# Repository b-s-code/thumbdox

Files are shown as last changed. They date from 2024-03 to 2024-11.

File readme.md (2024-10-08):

# ThumbDox

The ThumbDox is a (WIP) split keyboard based on the [ErgoDox](https://www.ergodox.io/).

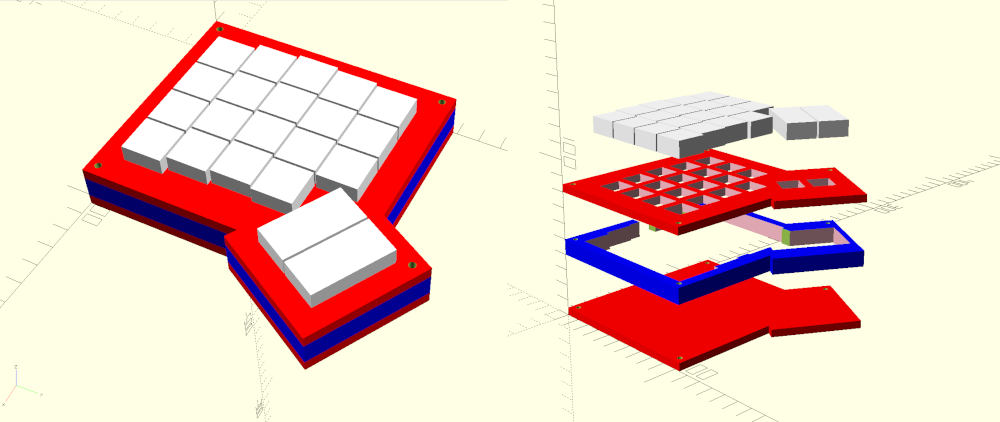
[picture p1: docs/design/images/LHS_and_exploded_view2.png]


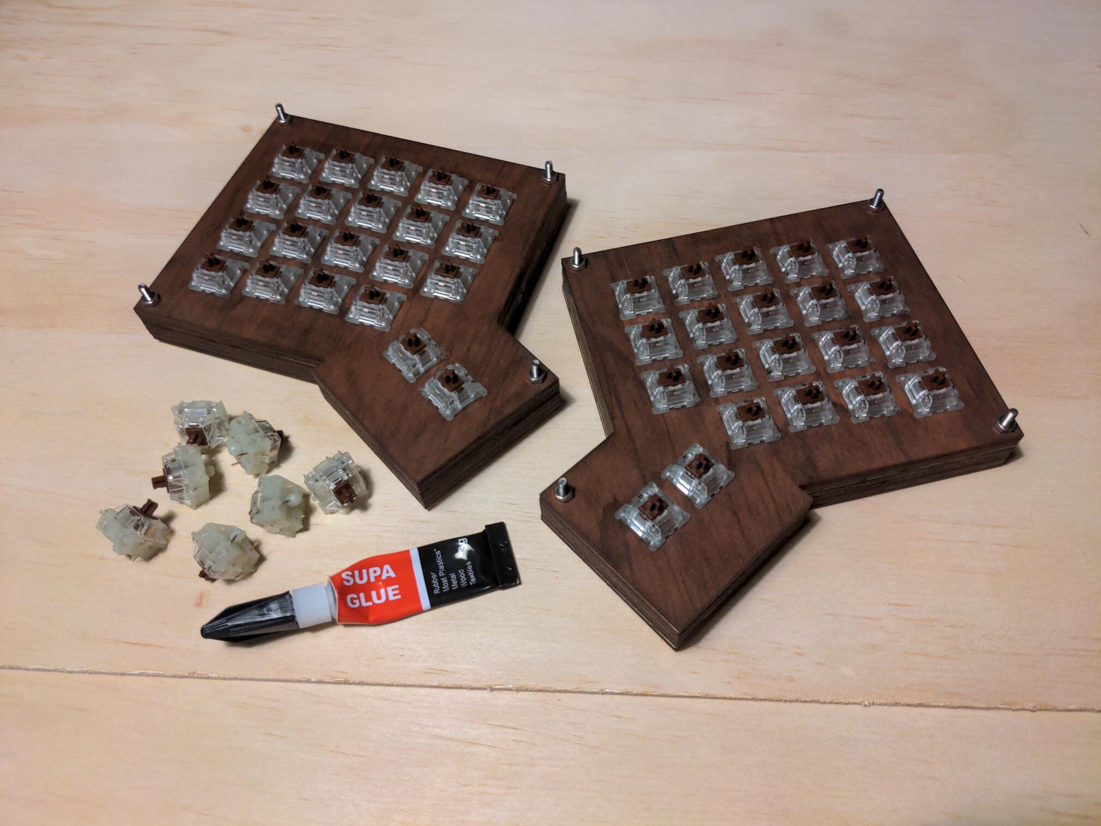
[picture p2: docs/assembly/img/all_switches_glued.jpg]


My aims in producing ThumbDox:

1.  Eliminate most of the keys I don't use.
2.  Retain the two 2U thumb keys.
3.  Document the design and production of the keyboard.  Many existing projects are similar, but I could not find anything exactly like what I wanted.  Perhaps showing my process here may save someone else reinventing the ThumbDox.

## Similar projects

[ErgoDox](https://www.ergodox.io/) [Squiggle](https://github.com/ibnuda/Squiggle) [Zen](https://legonut.gitbooks.io/zen-keyboard/content/) [Gergo](https://qmk.fm/keyboards/gergo/)

## Development

See [docs/design/dev_env_setup.md](docs/design/model_dev_env_setup.md) for details on going from Python source to DXF files suitable for laser cutting.

See [docs/design/qmk_dev_env_setup.md](docs/firmware/qmk_dev_env_setup.md) for details on working with the QMK firmware that powers ThumbDox.

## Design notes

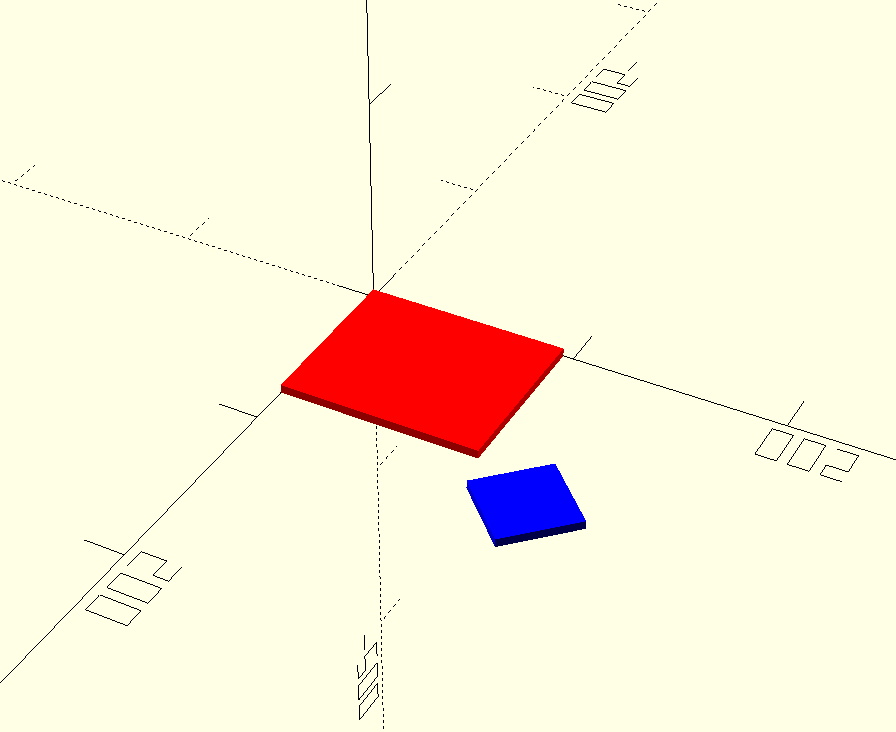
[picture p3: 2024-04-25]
docs/design/images/column_group_minuends_untuned_positions_no_padding.png

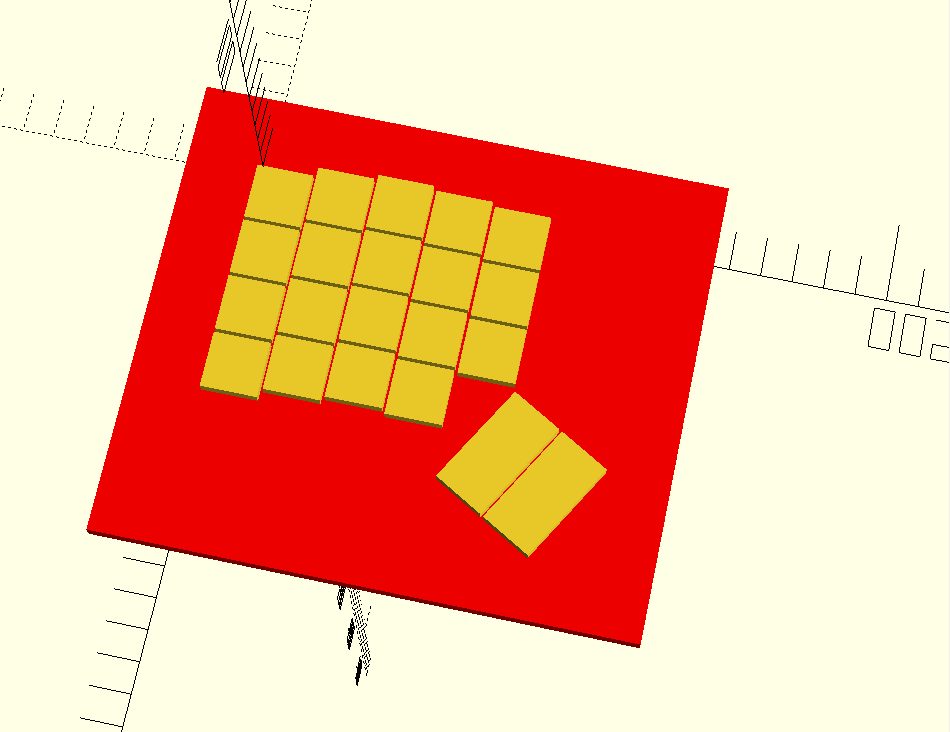
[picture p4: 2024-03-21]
docs/design/images/key_positions_tuned.png

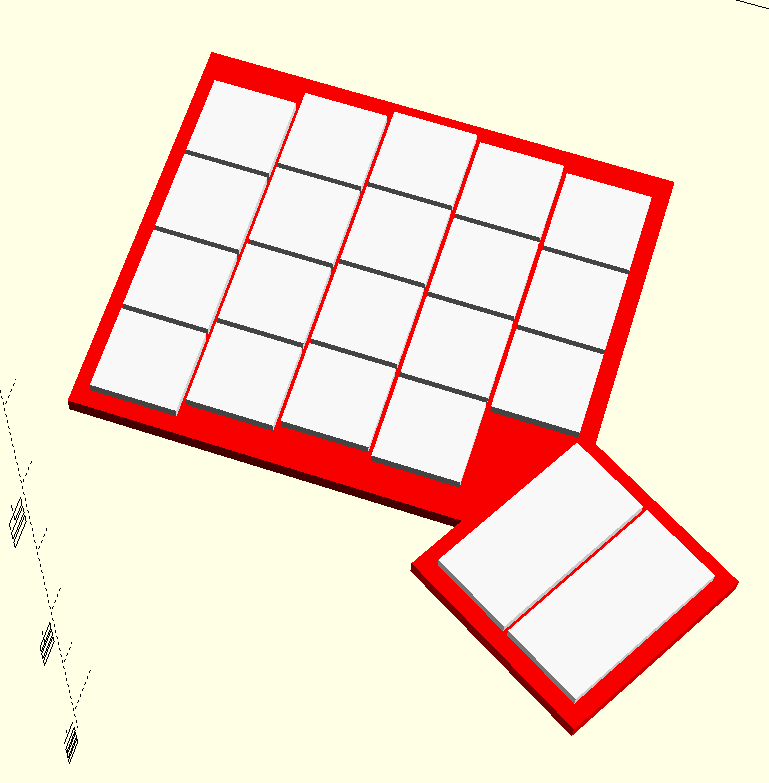
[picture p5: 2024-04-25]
docs/design/images/keycaps_and_base.png

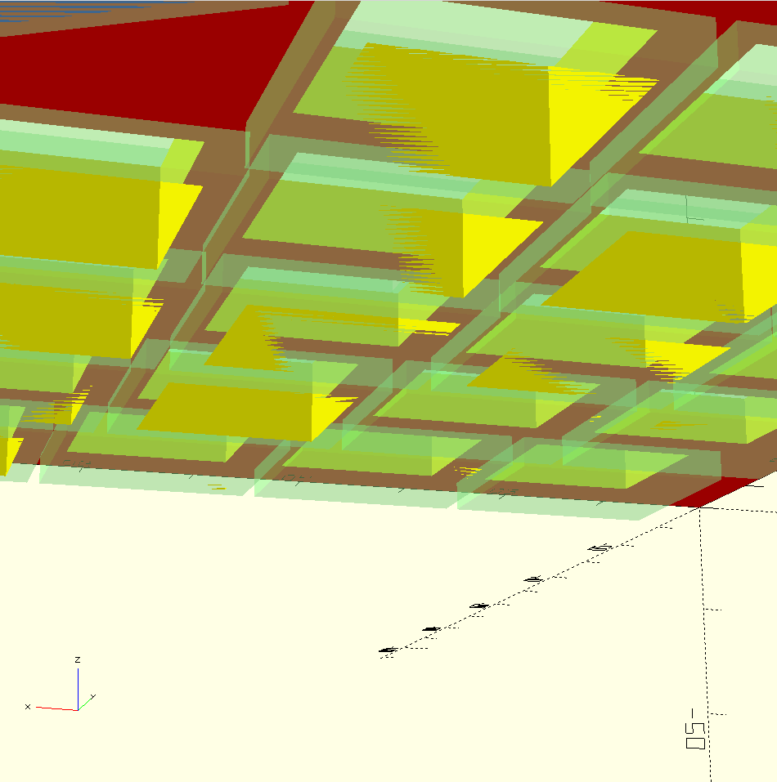
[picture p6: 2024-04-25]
docs/design/images/transparent_keycaps2.png

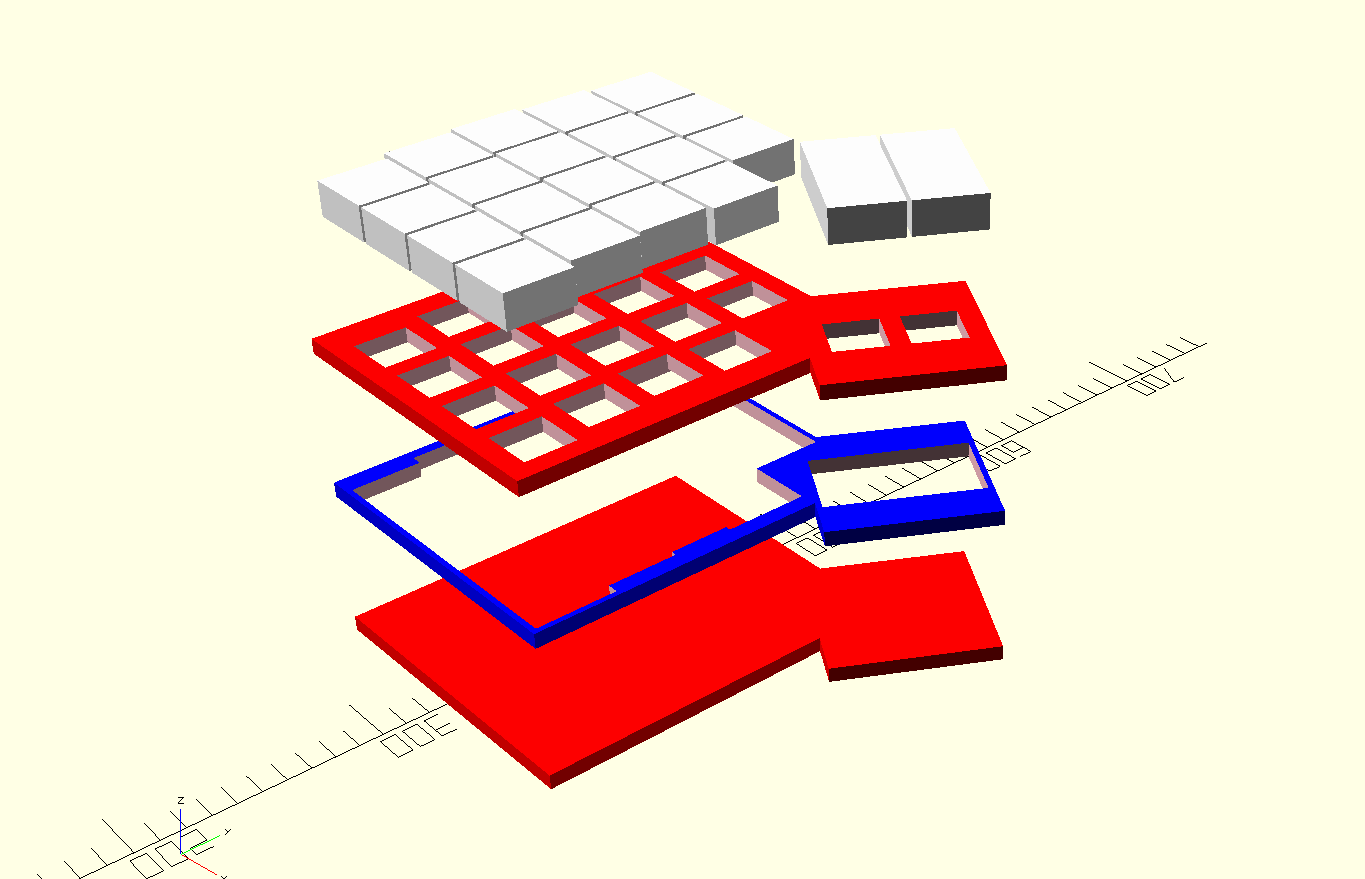
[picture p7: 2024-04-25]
docs/design/images/first_exploded_render.png

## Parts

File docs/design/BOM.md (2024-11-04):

# Bill of materials

## Parts

| Part | Description | Quantity | Unit cost | Cost | Source |
|---|---|---|---|---|---|
| 1N4148 Small Signal Diode | One of these diodes connects each keyswitch to a row wire. | 42 | $0.15 AUD | $6.30 AUD | https://www.altronics.com.au/p/z0101-1n914-1n4148-small-signal-diode/ |
| OEM Profile R1 Row1 Caps 1.25u/1.5u/1.75u/2.0u/2.25u/2.75u PBT Keycaps for Mechanical Keyboard Supplementary Keys Alt Ctrl Shift | Keycaps for thumb cluster. | 4 | - | $20.49 AUD | https://www.aliexpress.com/item/1005004784994416.html |
| OEM Profile 75 Key Blank PBT Ortholinear Layout Keycaps For Mechanical Keyboard XD75 ID75 Planck Preonic Niu40 YMD40v2 40% DIY | Keycaps for finger clusters.  Only need some of these. | 1 set | - | $37.95 AUD | https://www.aliexpress.com/item/1005001914177551.html |
| 10 100 Pcs TRRS 3.5 MM Audio Jack Connector Through Holes PCB Horizontal 4 Conductor Right Angle No Internal Switch 4 Pole | TRRS jack set, only need 2 pieces. | 1 set | - | $6.11 AUD | https://www.aliexpress.com/item/33029465106.html |
| Raspberry Pi Pico microcontroller | One for each keyboard half. | 2 | $8.95 AUD | $17.90 AUD | https://www.altronics.com.au/p/z6421-raspberry-pi-pico-microcontroller-board/ |
| Male-male Micro USB to USB Type A cable | Connects main microcontroller to PC. | 1 | N/A | N/A | - |
| Male-male TRRS cable | Connects left and right halves of keyboard. | 1 | N/A | N/A | - |
| 3mm plywood 1200mm x 810mm | Gets laser cut to produce case and switch plate parts. | 1 | $18.00 AUD | $18.00 AUD | Bunnings |
| M3 x 25mm bolts and nuts | Joins case and switch plate layers - requires head diameter <=6mm, thread length >20mm. | 8 | N/A | $3.90 AUD | https://www.bunnings.com.au/pinnacle-m3-x-25mm-stainless-steel-hex-head-bolts-and-nuts-12-pack_p0247296 |
| Original Brand NEW Cherry MX Mechanical Keyboard Switches Silver Red Black Blue Brown Linear Tactile Cherry Clear SMD RGB Switch | Brown MX compatible key switches. | 42 (bought 60) | ~$0.30 AUD | $17.91 AUD | https://www.aliexpress.com/item/1005006255961111.html |

## Tools and general consumables

| Item | Notes |
|---|---|
| Soldering iron | - |
| Lead free solder | - |
| Knife | - |
| Hot glue gun | - |
| Hot glue | To fix MCU and TRRS jack in place. |
| Wire (insulated)  | - |
| Wire (uninsulated)  | - |
| Heat-shrink tubing  | - |

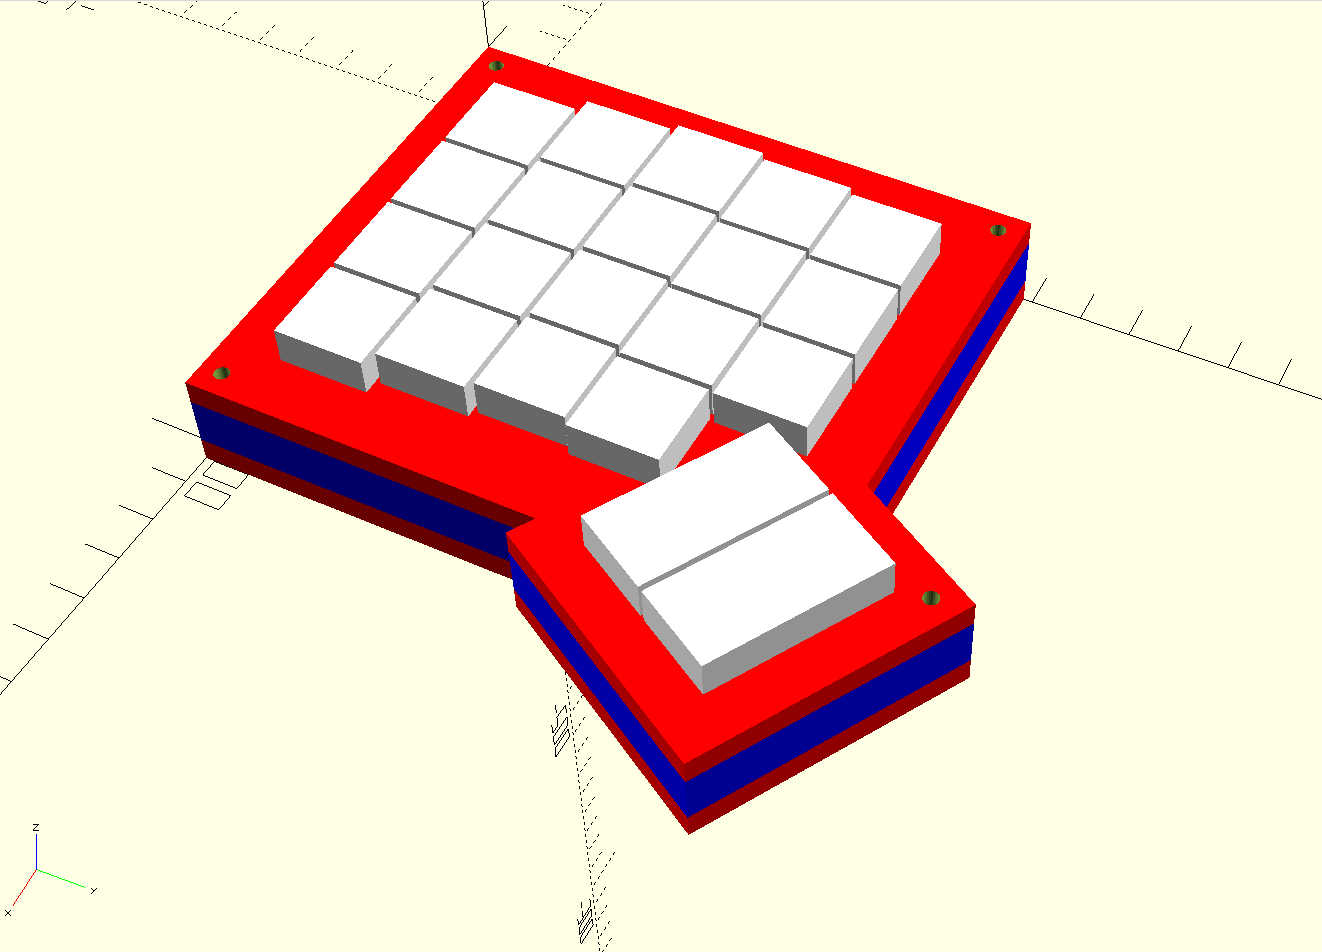
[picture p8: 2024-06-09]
docs/design/images/flush_parts3.png

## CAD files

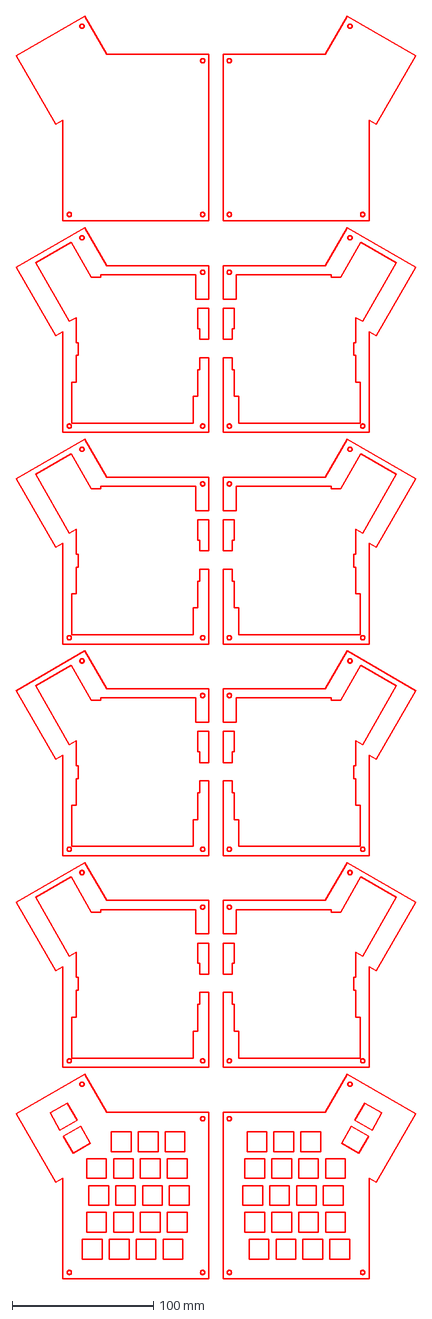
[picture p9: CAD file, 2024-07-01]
3D_model/concat_parts_3mm.dxf
283.3 x 895.1 mm

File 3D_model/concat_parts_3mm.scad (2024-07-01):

projection()
union() {
	cube(size = [0, 0, 0]);
	translate(v = [0, 0, 0]) {
		union() {
			difference() {
				union() {
					cube(size = [0, 0, 0]);
					color(alpha = 1.0, c = "red") {
						translate(v = [0.0, 0.0, 0]) {
							rotate(a = [0, 0, -0.0]) {
								cube(size = [103.7, 118.25, 5]);
							}
						}
					}
					color(alpha = 1.0, c = "red") {
						translate(v = [60.0, 96.5, 0]) {
							rotate(a = [0, 0, -30.0]) {
								cube(size = [56.1, 56.1, 5]);
							}
						}
					}
				}
				union() {
					cube(size = [0, 0, 0]);
					translate(v = [4.5, 4.5, -1]) {
						cylinder($fn = 30, h = 15, r = 1.5);
					}
					translate(v = [99, 4.5, -1]) {
						cylinder($fn = 30, h = 15, r = 1.5);
					}
					translate(v = [90, 138, -1]) {
						cylinder($fn = 30, h = 15, r = 1.5);
					}
					translate(v = [4.5, 113.5, -1]) {
						cylinder($fn = 30, h = 15, r = 1.5);
					}
					translate(v = [0.0, 0.0, 0]) {
						rotate(a = [0, 0, -0.0]) {
							union() {
								cube(size = [0, 0, 0]);
								translate(v = [16.0, 11.5, 0]) {
									color(alpha = 1.0, c = "pink") {
										translate(v = [2.5250000000000004, 2.5250000000000004, 0]) {
											translate(v = [0, 0, -2.5]) {
												cube(size = [14, 14, 10]);
											}
										}
									}
								}
								translate(v = [35.05, 11.5, 0]) {
									color(alpha = 1.0, c = "pink") {
										translate(v = [2.5250000000000004, 2.5250000000000004, 0]) {
											translate(v = [0, 0, -2.5]) {
												cube(size = [14, 14, 10]);
											}
										}
									}
								}
								translate(v = [54.1, 11.5, 0]) {
									color(alpha = 1.0, c = "pink") {
										translate(v = [2.5250000000000004, 2.5250000000000004, 0]) {
											translate(v = [0, 0, -2.5]) {
												cube(size = [14, 14, 10]);
											}
										}
									}
								}
								translate(v = [73.15, 11.5, 0]) {
									color(alpha = 1.0, c = "pink") {
										translate(v = [2.5250000000000004, 2.5250000000000004, 0]) {
											translate(v = [0, 0, -2.5]) {
												cube(size = [14, 14, 10]);
											}
										}
									}
								}
								translate(v = [13.0, 30.55, 0]) {
									color(alpha = 1.0, c = "pink") {
										translate(v = [2.5250000000000004, 2.5250000000000004, 0]) {
											translate(v = [0, 0, -2.5]) {
												cube(size = [14, 14, 10]);
											}
										}
									}
								}
								translate(v = [32.05, 30.55, 0]) {
									color(alpha = 1.0, c = "pink") {
										translate(v = [2.5250000000000004, 2.5250000000000004, 0]) {
											translate(v = [0, 0, -2.5]) {
												cube(size = [14, 14, 10]);
											}
										}
									}
								}
								translate(v = [51.1, 30.55, 0]) {
									color(alpha = 1.0, c = "pink") {
										translate(v = [2.5250000000000004, 2.5250000000000004, 0]) {
											translate(v = [0, 0, -2.5]) {
												cube(size = [14, 14, 10]);
											}
										}
									}
								}
								translate(v = [70.15, 30.55, 0]) {
									color(alpha = 1.0, c = "pink") {
										translate(v = [2.5250000000000004, 2.5250000000000004, 0]) {
											translate(v = [0, 0, -2.5]) {
												cube(size = [14, 14, 10]);
											}
										}
									}
								}
								translate(v = [11.5, 49.6, 0]) {
									color(alpha = 1.0, c = "pink") {
										translate(v = [2.5250000000000004, 2.5250000000000004, 0]) {
											translate(v = [0, 0, -2.5]) {
												cube(size = [14, 14, 10]);
											}
										}
									}
								}
								translate(v = [30.55, 49.6, 0]) {
									color(alpha = 1.0, c = "pink") {
										translate(v = [2.5250000000000004, 2.5250000000000004, 0]) {
											translate(v = [0, 0, -2.5]) {
												cube(size = [14, 14, 10]);
											}
										}
									}
								}
								translate(v = [49.6, 49.6, 0]) {
									color(alpha = 1.0, c = "pink") {
										translate(v = [2.5250000000000004, 2.5250000000000004, 0]) {
											translate(v = [0, 0, -2.5]) {
												cube(size = [14, 14, 10]);
											}
										}
									}
								}
								translate(v = [68.65, 49.6, 0]) {
									color(alpha = 1.0, c = "pink") {
										translate(v = [2.5250000000000004, 2.5250000000000004, 0]) {
											translate(v = [0, 0, -2.5]) {
												cube(size = [14, 14, 10]);
											}
										}
									}
								}
								translate(v = [13.0, 68.65, 0]) {
									color(alpha = 1.0, c = "pink") {
										translate(v = [2.5250000000000004, 2.5250000000000004, 0]) {
											translate(v = [0, 0, -2.5]) {
												cube(size = [14, 14, 10]);
											}
										}
									}
								}
								translate(v = [32.05, 68.65, 0]) {
									color(alpha = 1.0, c = "pink") {
										translate(v = [2.5250000000000004, 2.5250000000000004, 0]) {
											translate(v = [0, 0, -2.5]) {
												cube(size = [14, 14, 10]);
											}
										}
									}
								}
								translate(v = [51.1, 68.65, 0]) {
									color(alpha = 1.0, c = "pink") {
										translate(v = [2.5250000000000004, 2.5250000000000004, 0]) {
											translate(v = [0, 0, -2.5]) {
												cube(size = [14, 14, 10]);
											}
										}
									}
								}
								translate(v = [70.15, 68.65, 0]) {
									color(alpha = 1.0, c = "pink") {
										translate(v = [2.5250000000000004, 2.5250000000000004, 0]) {
											translate(v = [0, 0, -2.5]) {
												cube(size = [14, 14, 10]);
											}
										}
									}
								}
								translate(v = [14.5, 87.7, 0]) {
									color(alpha = 1.0, c = "pink") {
										translate(v = [2.5250000000000004, 2.5250000000000004, 0]) {
											translate(v = [0, 0, -2.5]) {
												cube(size = [14, 14, 10]);
											}
										}
									}
								}
								translate(v = [33.55, 87.7, 0]) {
									color(alpha = 1.0, c = "pink") {
										translate(v = [2.5250000000000004, 2.5250000000000004, 0]) {
											translate(v = [0, 0, -2.5]) {
												cube(size = [14, 14, 10]);
											}
										}
									}
								}
								translate(v = [52.6, 87.7, 0]) {
									color(alpha = 1.0, c = "pink") {
										translate(v = [2.5250000000000004, 2.5250000000000004, 0]) {
											translate(v = [0, 0, -2.5]) {
												cube(size = [14, 14, 10]);
											}
										}
									}
								}
							}
						}
					}
					translate(v = [60.0, 96.5, 0]) {
						rotate(a = [0, 0, -30.0]) {
							union() {
								cube(size = [0, 0, 0]);
								translate(v = [18.525, 9.0, 0]) {
									color(alpha = 1.0, c = "pink") {
										translate(v = [2.5250000000000004, 2.5250000000000004, 0]) {
											translate(v = [0, 0, -2.5]) {
												cube(size = [14, 14, 10]);
											}
										}
									}
								}
								translate(v = [18.525, 28.05, 0]) {
									color(alpha = 1.0, c = "pink") {
										translate(v = [2.5250000000000004, 2.5250000000000004, 0]) {
											translate(v = [0, 0, -2.5]) {
												cube(size = [14, 14, 10]);
											}
										}
									}
								}
							}
						}
					}
				}
			}
			translate(v = [-10, 0, 0]) {
				mirror(v = [1, 0, 0]) {
					difference() {
						union() {
							cube(size = [0, 0, 0]);
							color(alpha = 1.0, c = "red") {
								translate(v = [0.0, 0.0, 0]) {
									rotate(a = [0, 0, -0.0]) {
										cube(size = [103.7, 118.25, 5]);
									}
								}
							}
							color(alpha = 1.0, c = "red") {
								translate(v = [60.0, 96.5, 0]) {
									rotate(a = [0, 0, -30.0]) {
										cube(size = [56.1, 56.1, 5]);
									}
								}
							}
						}
						union() {
							cube(size = [0, 0, 0]);
							translate(v = [4.5, 4.5, -1]) {
								cylinder($fn = 30, h = 15, r = 1.5);
							}
							translate(v = [99, 4.5, -1]) {
								cylinder($fn = 30, h = 15, r = 1.5);
							}
							translate(v = [90, 138, -1]) {
								cylinder($fn = 30, h = 15, r = 1.5);
							}
							translate(v = [4.5, 113.5, -1]) {
								cylinder($fn = 30, h = 15, r = 1.5);
							}
							translate(v = [0.0, 0.0, 0]) {
								rotate(a = [0, 0, -0.0]) {
									union() {
										cube(size = [0, 0, 0]);
										translate(v = [16.0, 11.5, 0]) {
											color(alpha = 1.0, c = "pink") {
												translate(v = [2.5250000000000004, 2.5250000000000004, 0]) {
													translate(v = [0, 0, -2.5]) {
														cube(size = [14, 14, 10]);
													}
												}
											}
										}
										translate(v = [35.05, 11.5, 0]) {
											color(alpha = 1.0, c = "pink") {
												translate(v = [2.5250000000000004, 2.5250000000000004, 0]) {
													translate(v = [0, 0, -2.5]) {
														cube(size = [14, 14, 10]);
													}
												}
											}
										}
										translate(v = [54.1, 11.5, 0]) {
											color(alpha = 1.0, c = "pink") {
												translate(v = [2.5250000000000004, 2.5250000000000004, 0]) {
													translate(v = [0, 0, -2.5]) {
														cube(size = [14, 14, 10]);
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

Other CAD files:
3D_model/full_model.scad
3D_model/model.scad

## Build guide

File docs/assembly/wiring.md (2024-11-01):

# Wiring

This document details wiring:

- within each keyboard half
 - i.e. how rows/columns are connected to each MCU
- between the two keyboard halves
 - i.e. how each MCU is is wired to its respective TRRS jack

## Software support for split keyboards

Won't flesh this out fully here since it's a wiring doc.  But there is code required to set this up.  See:

- https://docs.qmk.fm/features/split_keyboard
- https://docs.qmk.fm/drivers/serial

## TRRS connections

### TRRS communication mode

Each MCU needs a TRRS jack wired to it.

The Raspberry Pi Pico cannot use I2C over the TRRS connection because it is not supported (either in QMK or at all, not sure which).

Thus, serial communication must be used instead.

Pull up resistors are not required since using serial rather than I2C.

Note: ThumbDox uses *full duplex* serial communication (2 wires) which is purportedly faster.  It's unclear whether this is really necessary in practice.

### Which MCU pins can be used for connecting to TRRS jacks?

Let's consider, from the primary MCU's perspective, the purpose of the 4 wires between the two keyboard halves.

1. wire for transmitting data to the secondary MCU 
2. wire for receiving data from the secondary MCU
3. wire for ground
4. wire for supplying power to the secondary MCU

1, 2, and 3 can be wired to GPIO/ground pins.  But which pin to use for 4 is less clear.

Some split keyboards using Pico MCUs have VSYS wired to VSYS.  Others have 3v3 wired to 3v3.

People online argue about what's "right".  Neither setup is unanimously considered "preferred" or even "unambiguously okay".

Somewhat arbitrarily, 3v3 to 3v3 has been selected as the wiring scheme for supplying ThumbDox's secondary MCU with power.

## MCU pin assignment scheme

Note:

- "Centre-most" means centre of the two halves.  Not centre of one half of the keyboard.
- Thumb keys exist on their own row.
- Centre-most thumb key is wired to centre-most index column.
- The other thumb key is wired to home index column.

| Pin number | Pin name | Use |
|----|-----|----|
| 38 | GND | TRRS - ground |
| 36 | 3V3(OUT) | TRRS - power transmission |
| 1  | GP0 | Serial TX |
| 2  | GP1 | Serial RX |
| 16 | GP12 | Top row |
| 17 | GP13 | Home row |
| 19 | GP14 | Below home row |
| 20 | GP15 | Bottom row |
| 15 | GP11 | Thumb row |
| 26 | GP20 | Pinky column |
| 25 | GP19 | Ring column |
| 24 | GP18 | Middle column |
| 22 | GP17 | Index home column |
| 21 | GP16 | Index centre-most column |

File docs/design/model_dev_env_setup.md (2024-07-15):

# Setting up the development environment for 3D modelling

The [solidpython2 library](https://github.com/jeff-dh/SolidPython) is used to generate OpenSCAD code.

OpenSCAD is used to define the 3D models.

## Setup steps

### Install OpenSCAD

I installed OpenSCAD version 2021.01 with:

```
$ sudo apt-get install openscad
```

### Set up Python environment for generating OpenSCAD code

```
# cd to root of ThumbDox repo.

# Create a virtual environment to install dependencies.
$ python3 -m venv ./venv

# Activate the virtual environment.
$ source ./venv/bin/activate

# Actually install the dependencies.  This installs both packages needed
# for 3D modelling and packages needed for building the firmware to the
# virtual environment.
$ pip install -r requirements.txt
```

## Actual development steps

### Editing the 3D model source

The source code for the 3D model is `3D_model/model.py`.  Editing that Python file is necessary to change the model (it is not intended that this project's generated OpenSCAD code be manually edited).

### Compiling the 3D model source to OpenSCAD code

(With the virtual environment for the project activated.)

`$ ./venv/bin/python3 3D_model/model.py`

### Viewing the rendered OpenSCAD code

This model shows the entire keyboard in 3D.

`$ openscad 3D_model/model.scad`

This model shows the 2D projections of parts that can be produced by laser cutting.

`$ openscad 3D_model/concat_parts_3mm.scad`

### Exporting the OpenSCAD parts model to DXF for laser cutting

Open 3D_model/concat_parts_3mm.scad in OpenSCAD, press F6 to render the model.

Then click File > Export > Export as DXF.

Open the DXF file with LibreCAD.  Use the rectangular select tool to select all lines.  Right-click the only layer in the layer list then click Edit Layer Attributes.  Change the colour to Red.  Save and close the DXF file.

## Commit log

2024-03-20 couple classes for modelling key switch holes
2024-03-20 add model code and compilation instructions
    [model.scad]
2024-03-20 1U key column switch holes cut, but not tuned
    [model.scad]
2024-03-20 thumb key hole class
    [model.scad]
2024-03-20 encapsulate switchplate, signpost future work
    [model.scad]
2024-03-21 add diagnostic keycap rendering, do rough tuning
    [model.scad]
2024-03-21 simpler view for tuning
    [model.scad]
2024-03-21 couple keycap/switch hole tuning for columns
2024-03-21 column tuning
    [model.scad]
2024-03-21 dict for thumb data, fix thumb z offset bug
    [model.scad]
2024-03-21 less ridciulous intial switch plate dimensions
    [model.scad]
2024-03-21 started sculpting outside edges of switch plate
    [model.scad]
2024-03-31 visualise column group minuends
    [model.scad]
2024-03-31 less ridiculous thumb column group positioning
    [model.scad]
2024-03-31 determined rotation convention empirically
    [model.scad]
2024-03-31 mostly comments
    [model.scad]
2024-03-31 sketch removal of material for key switch holes, progress pics
    [model.scad]
2024-04-01 untidy working implementation of render_subtrahend_plate
    [model.scad]
2024-04-01 z-fighting occurs, probably not enough space for wiring if it extends beyond key space boundaries
    [model.scad]
2024-04-01 possible solution for spacer subtrahend logic
    [model.scad]
2024-04-06 easy base plate
    [model.scad]
2024-04-06 signpost future work
    [model.scad]
2024-04-09 WIP keyboard render strat, screenshots
    [model.scad]
2024-04-16 transparent keycaps, cleanup
    [model.scad]
2024-04-23 thumb position looks better
    [model.scad]
2024-04-23 pass keycap unit length, use it
    [model.scad]
2024-04-23 fix 2U 3U 4U... keycap length bug
    [model.scad]
2024-04-25 support simultaneously rendering parts of different types
    [model.scad]
2024-04-25 make explosion distance easily adjustable, signpost future work
    [model.scad]
2024-04-27 more padding
    [model.scad]
2024-04-27 thicker spacer,
    [model.scad]
2024-04-27 remove execess switch plate material
    [model.scad]
2024-04-28 thoughts on spacer height
2024-05-27 spacer thickness calculation
    [model.scad]
2024-05-28 separate function for spacer cutouts
    [model.scad]
2024-05-28 fix bug from unnecessary transformation, organise hardcoded dat
    [model.scad]
2024-05-28 shape the TRRS jack slot
    [model.scad]
2024-06-01 begin planning laser cut sheet construction with bolts as joins
2024-06-01 bolt hole function works for spacer and plate but not base
    [model.scad]
2024-06-01 bolt hole function works for base too
    [model.scad]
2024-06-01 M3 bolt hole size. Positions still TODO
    [model.scad]
2024-06-01 begin bill of materials
2024-06-01 untested, reasonable looking bolt hole positions
    [model.scad]
2024-06-06 found example bolt head diameters online and took a comfortable upper bound
2024-06-06 WIP MCU placement idea
    [model.scad]
2024-06-09 more space
    [model.scad]
2024-06-09 satisfied with TRRS, MCU slot positions
    [model.scad]
2024-06-09 unhide base
    [model.scad]
2024-06-09 adjust spacer cutout for wiring
2024-06-09 render each part flush with neighbours
    [model.scad]
2024-06-09 render RHS of keyboard too
    [model.scad]
2024-06-10 update materials
2024-06-10 update BOM again
2024-06-12 build .scad files for each part
    [base.scad, full_model.scad, plate.scad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]
2024-06-12 move RHS closer to LHS in parts' files
    [base.scad, plate.scad, spacer.scad]
2024-06-12 make .scad files for each part rep. a 2D view
    [base.scad, plate.scad, spacer.scad]
2024-06-12 update BOM: keycaps, TRRS jacks
2024-06-16 lay out 2D projections in just one file
    [base.scad, concat_parts.scad, plate.scad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]
2024-06-16 switch plate 3mm, other layers 6mm
    [concat_parts_3mm.scad, concat_parts_6mm.scad]
2024-06-16 manually exported DXFs from openscad
    [concat_parts_3mm.dxf, concat_parts_6mm.dxf]
2024-07-01 all parts on 3mm ply
    [concat_parts.scad, concat_parts_3mm.dxf, concat_parts_3mm.scad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]
2024-07-01 new DXF, reflective of what was actually produced
    [concat_parts_3mm.dxf]
2024-07-01 update BOM w.r.t. plywood actually used
2024-09-09 Sketch assembly process.
2024-09-16 No resistors to be included in WAD. RP2040 is ARM not AVR, hence must use QMK's serial driver, not the I2C driver. Pull-up resistors are only required for I2C wiring, not serial wiring.
2024-09-16 Add wiring doc.
2024-09-16 More details on TRRS wiring.
2024-10-22 Define intended pin usage for TRRS comms.
2024-10-22 Illustrate wiring onto TRRS jacks.
2024-10-22 Sketch idea for row/col-pin mapping.
2024-10-31 Initial overall wiring diagram.
2024-10-31 Define wiring between rows and MCUs.
2024-11-01 Edit wiring doc.
2024-11-04 Uninsulated wire for connecting switches to matrix. Insulated wire for connecting matrix to MCU.
2024-11-04 Clarify assembly process.
2024-11-04 Add column wires to diagram.
